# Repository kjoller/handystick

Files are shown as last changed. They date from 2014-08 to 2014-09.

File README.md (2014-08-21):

HandyStick is yet another small development board with an AtmegaX8 (Atmega88,
Atmega168, Atmega328). The board is targeted towards use with vUsb, a software
implemented USB stack.

It is cheap to manufacture, fitting two on a cheap 5x5cm 2-layer pcb, and using
easy-to-source parts.

Possible uses:

* Using projects like USBAspLoader, you can get a USB programmable AVR board for less than $3 in parts.
* You can use this for USB HID-devices, such as joysticks, gamepads or even a full-featured MAME cabinet
* USB dataloggers
* For more ideas, see the vUSB web site.

The first panel is panelised with mouse bites (tab routing), so not all PCB
services will take it. I have ordered the first batch on DirtyPCBs. 

(For added vendor flexibility, it would be wise to panelize it using only
silkscreen seperators. with just silkscreen, 5 should fit easily on a 5x10cm
board, making it even cheaper.)

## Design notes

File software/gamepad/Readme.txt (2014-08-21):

This is the README file for the HIDKeys USB device.

HIDKeys is an example application for implementing an USB keyboard conforming
to the "USB Device Class Definition for Human Interface Devices (HID)". It is
based on Objective Development's firmware-only USB driver for Atmel's AVR
microcontrollers and accepts up to 17 key inputs on an ATMega8. The firmware
should be easily portable to an ATTiny2313 or other tiny devices. Since it
implements a standards compliant keyboard, no separate host software is
needed.

Objective Development's USB driver is a firmware-only implementation of the
USB 1.1 standard (low speed device) on cheap single chip microcomputers of
Atmel's AVR series, such as the ATtiny2313 or even some of the small 8 pin
devices. It implements the standard to the point where useful applications can
be implemented. See the file "usbdrdv/usbdrv.h" for features and limitations.

BUILDING AND INSTALLING
=======================
The firmware for HIDKeys requires avr-gcc and avr-libc (a C-library for
the AVR controller). Please read the instructions at
http://www.nongnu.org/avr-libc/user-manual/install_tools.html for how to
install the GNU toolchain (avr-gcc, assembler, linker etc.) and avr-libc.
If you are on Windows, download WinAVR (see http://winavr.sourceforge.net/).

Once you have the GNU toolchain for AVR microcontrollers installed, you can
run "make". You may have to edit the Makefile to use your preferred downloader
with "make flash". Our current version is built for uisp with the AVR910
serial programmer connected through a USB to serial adapter to a Mac running
Mac OS X. Before you download the firmware, run "make fuse" to configure the
device for an external crystal.

NEVER LET A DEVICE WITH THIS FIRMWARE ESCAPE YOUR LAB! It uses a Vendor-ID
which is dedicated to education only. See the remarks in usbconfig.h and the
design hints below.

FILES IN THE DISTRIBUTION
=========================
Readme.txt ........ The file you are currently reading.
main.c ............ Source code of the controller firmware.
Makefile .......... The makefile for compiling the firmware.
checksize ......... A utility to check the code size (used by Makefile).
usbconfig.h ....... Header file with configuration options for the driver.
usbdrv ............ USB driver -- See Readme.txt in that directory for info.
circuit ........... Circuit diagrams in PDF and EAGLE 4 format. A free version
                    of EAGLE is available for Linux, Mac OS X and Windows from
                    http://www.cadsoft.de/.
License.txt ....... Public license (GPL2) for all contents of this project.
Changelog.txt ..... Logfile documenting changes in soft-, firm- and hardware.

WHY SHOULD I IMPLEMENT MY DEVICE AS A HID?
==========================================
HID does not necessarily mean keyboards, mice and joysticks. Any device which
requires only a moderate transfer rate can be designed as HID. So, should you
make a HID or a custom device with its own driver? The answer depends mostly
on the targetted operating system.

The main advantage of a HID compliant device is that you don't need a kernel
driver on Windows. This means that you can start the controlling software
application WITHOUT installation by an Administrator, e.g. directly from CD.
Since other operating systems don't need a kernel driver for USB devices, this
advantage is mostly Windows-only. The main disadvantage is the added
complexity (you need to understand how Report Descriptors are built) and that
you must conform to the framework defined by the HID specification.

Writing your own driver (e.g. with libusb) gives you much more flexibility and
less complexity, but you must install a kernel driver on Windows.

HINTS FOR DESIGNING YOUR OWN HID
================================
Designing a keyboard, mouse or joystick is relatively easy. There are enough
example Report Descriptors available and you can start with these. But if you
design something like e.g. our PowerSwitch, you must try to fit it into the
framework of "HID Usages" defined in usb.org's "HID Usage Tables" document.
The hints given here are mostly for this case:

(1) Use usb.org's "HID Descriptor Tool" available from
http://www.usb.org/developers/hidpage/ to build the Report Descriptor. You can
save the descriptor as "C" header file in the "Save As..." dialog.

(2) NEVER declare your device as keyboard or mouse, unless it actually IS a
keyboard or mouse. Keyboards and mice are hogged by the operating system
immediately after they have been connected.

(3) If you convert a keyboard or mouse into something different (by modifying
the Report Descriptor), you must delete the device in the Windows Device
Manager. Otherwise Windows will still bind the keyboard or mouse driver to the
device because this binding is established to the Vendor- and Product-ID, not
the device class.

(4) NEVER use Objective Development's free shared VID/PID pair for HIDs. Since
Windows binds the driver by VID/PID, you would bind the HID driver instead of
libusb to the IDs.

(5) Windows is very strict (more than usb.org's Descriptor Tool) when checking
Report Descriptors. If the descriptor check fails, the device will not even be
listed as HID.

(6) Windows checks reports against the Report Descriptor. If your device sends
more or less data than specified in the descriptor, the message is discarded.

(7) Use a USB Sniffer if something does not work as expected. You can usually
see where the communication aborts.

(8) Here is an example Report Descriptor to start with. It defines one input
report with up to 7 bytes for receiving interrupts from the device and 3
feature reports for reading/writing data from/to the device in blocks of 7, 15
or 31 bytes. Each report is prefixed by its report ID for a total of 8, 16 or
32 bytes. All blocks are defined as opaque data buffers with no particular
usage.

    0x06, 0x00, 0xff,              // USAGE_PAGE (Vendor Defined Page 1)
    0x09, 0x01,                    // USAGE (Vendor Usage 1)
    0xa1, 0x01,                    // COLLECTION (Application)
    0x15, 0x00,                    //   LOGICAL_MINIMUM (0)
    0x26, 0xff, 0x00,              //   LOGICAL_MAXIMUM (255)
    0x75, 0x08,                    //   REPORT_SIZE (8)
    0x85, 0x01,                    //   REPORT_ID (1)
    0x95, 0x07,                    //   REPORT_COUNT (7)
    0x09, 0x00,                    //   USAGE (Undefined)
    0x82, 0x02, 0x01,              //   INPUT (Data,Var,Abs,Buf)
    0x85, 0x02,                    //   REPORT_ID (2)
    0x95, 0x07,                    //   REPORT_COUNT (7)
    0x09, 0x00,                    //   USAGE (Undefined)
    0xb2, 0x02, 0x01,              //   FEATURE (Data,Var,Abs,Buf)
    0x85, 0x03,                    //   REPORT_ID (3)
    0x95, 0x0f,                    //   REPORT_COUNT (15)
    0x09, 0x00,                    //   USAGE (Undefined)
    0xb2, 0x02, 0x01,              //   FEATURE (Data,Var,Abs,Buf)
    0x85, 0x04,                    //   REPORT_ID (4)
    0x95, 0x1f,                    //   REPORT_COUNT (31)
    0x09, 0x00,                    //   USAGE (Undefined)
    0xb2, 0x02, 0x01,              //   FEATURE (Data,Var,Abs,Buf)
    0xc0                           // END_COLLECTION

ABOUT THE LICENSE
=================
It is our intention to make our USB driver and this demo application
available to everyone. Moreover, we want to make a broad range of USB
projects and ideas for USB devices available to the general public. We
therefore want that all projects built with our USB driver are published
under an Open Source license. Our license for the USB driver and demo code is
the GNU General Public License Version 2 (GPL2). See the file "License.txt"
for details.

If you don't want to publish your source code under the GPL2, you can simply
pay money for AVR-USB. As an additional benefit you get USB PIDs for free,
licensed exclusively to you. See the file "CommercialLicense.txt" for details.

MORE INFORMATION
================
For more information about Objective Development's firmware-only USB driver
for Atmel's AVR microcontrollers please visit the URL

    http://www.obdev.at/products/avrusb/

A technical documentation of the driver's interface can be found in the file
"usbdrv/usbdrv.h".

--
(c) 2006, 2007 by OBJECTIVE DEVELOPMENT Software GmbH.
http://www.obdev.at/

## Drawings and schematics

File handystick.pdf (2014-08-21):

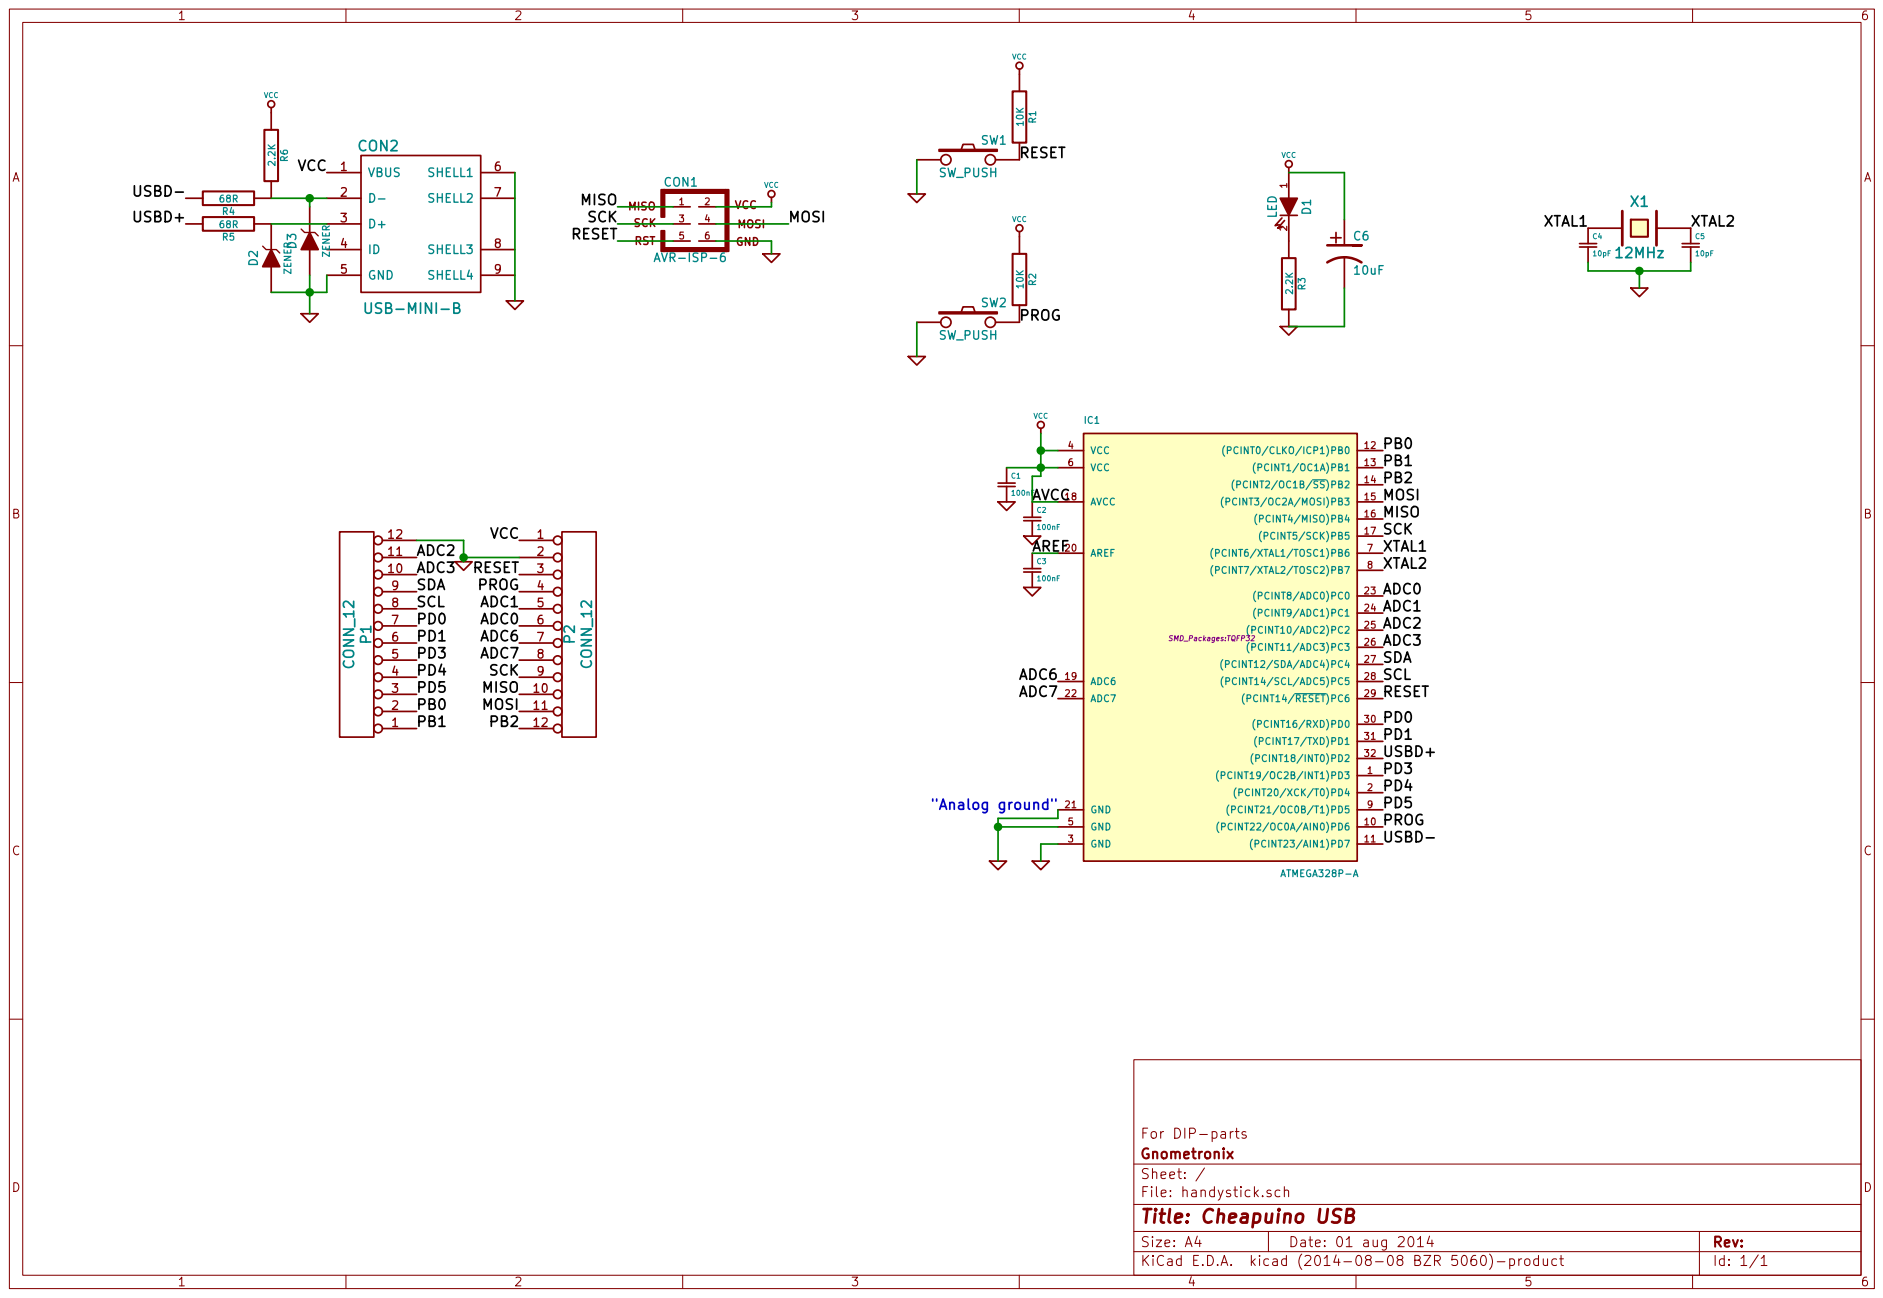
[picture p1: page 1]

File: handystick.sch Sheet: / Gnometronix For DIP-parts

Id: 1/1 Title: Cheapuino USB

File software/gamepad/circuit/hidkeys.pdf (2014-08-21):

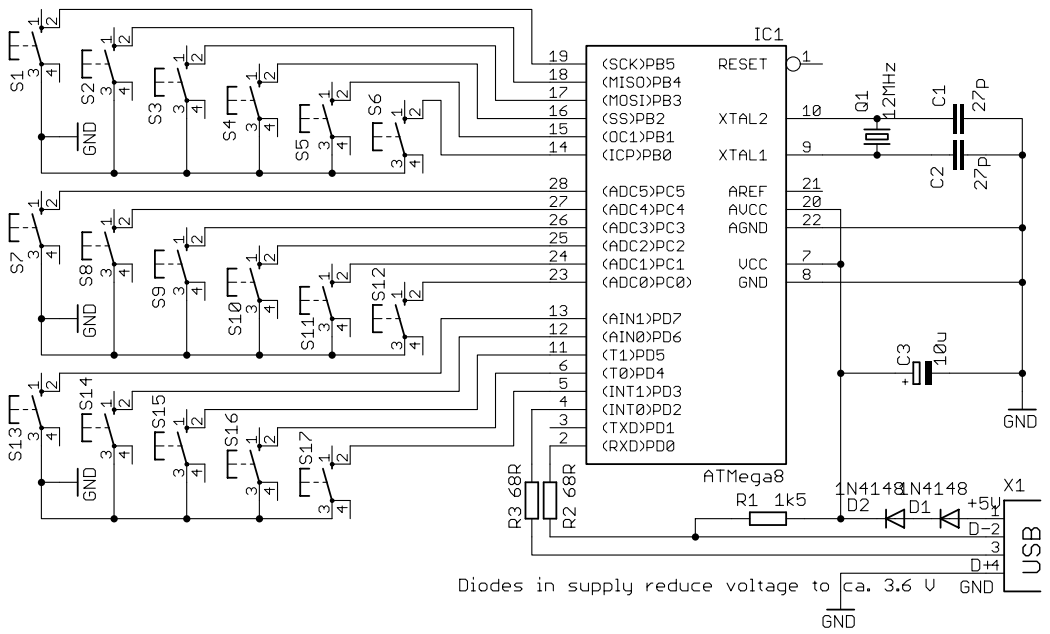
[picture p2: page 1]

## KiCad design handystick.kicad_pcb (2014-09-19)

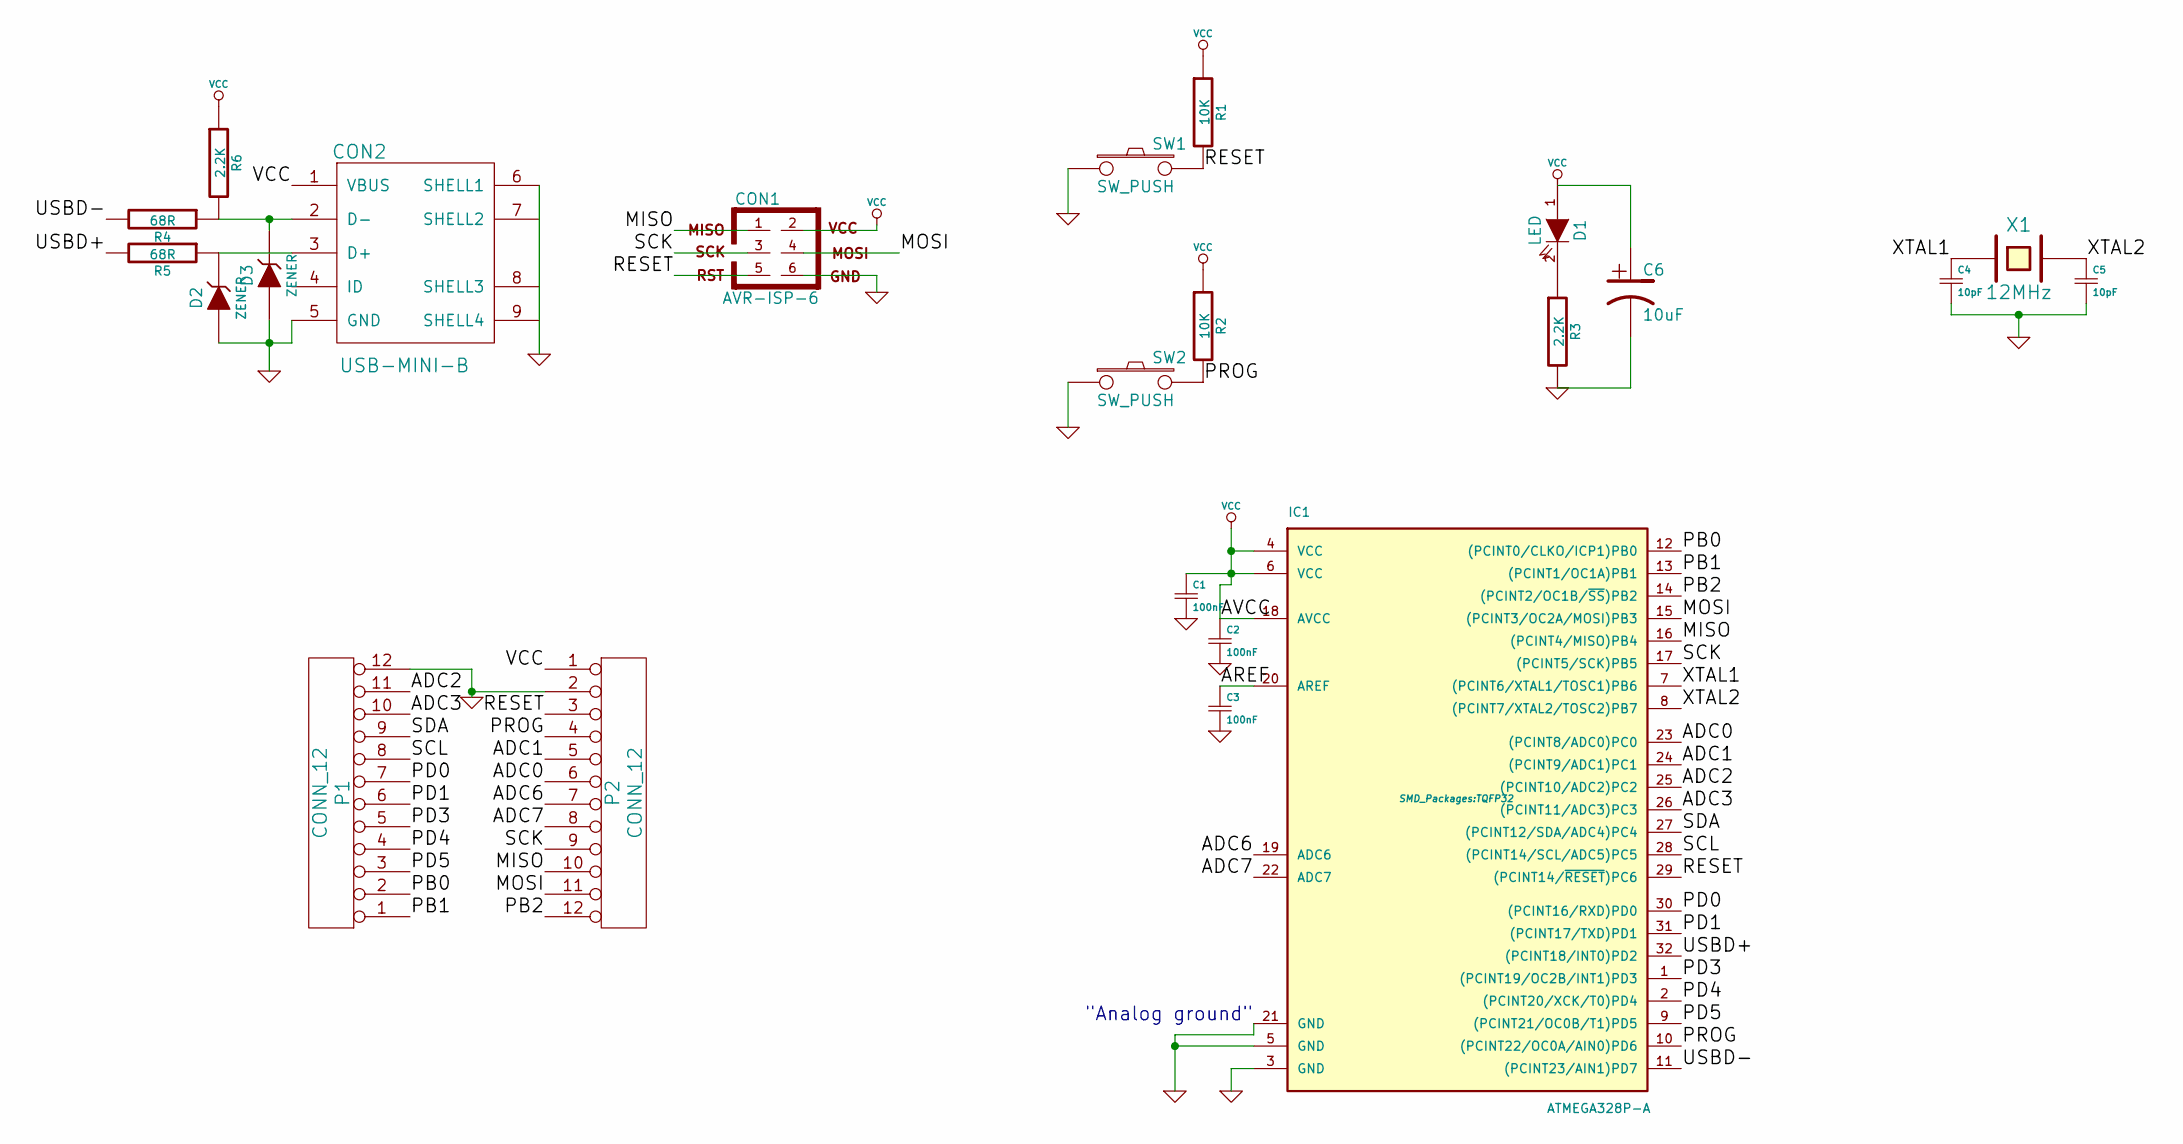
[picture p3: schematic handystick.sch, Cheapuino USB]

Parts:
C1, C2, C3: 100nF; SMD_0603
C4, C5: 10pF; c_0805
C6: 10uF
CON1: AVR-ISP-6; Pin_Header_Straight_2x03
CON2: USB-MINI-B; USB_Micro_B_SMD+DIP_long
D1: LED; SMD_0805
D2, D3: ZENER; Diode-MiniMELF_Handsoldering
IC1: ATMEGA328P-A; TQFP32
P1, P2: CONN_12; Pinrow_12p_oval
R1, R2: 10K; SMD_0603
R3, R6: 2.2K; SMD_0603
R4, R5: 68R; SMD_0805
SW1, SW2: SW_PUSH; 3x6_smd_button
X1: 12MHz; crystal_5032_2p

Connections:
/ADC0: IC1.23 ((PCINT8/ADC0)PC0), P2.6
/ADC1: IC1.24 ((PCINT9/ADC1)PC1), P2.5
/ADC2: IC1.25 ((PCINT10/ADC2)PC2), P1.11
/ADC3: IC1.26 ((PCINT11/ADC3)PC3), P1.10
/ADC6: IC1.19 (ADC6), P2.7
/ADC7: IC1.22 (ADC7), P2.8
/AREF: C3.1, IC1.20 (AREF)
/MISO: CON1.1, IC1.16 ((PCINT4/MISO)PB4), P2.10
/MOSI: CON1.4, IC1.15 ((PCINT3/OC2A/MOSI)PB3), P2.11
/PB0: IC1.12 ((PCINT0/CLKO/ICP1)PB0), P1.2
/PB1: IC1.13 ((PCINT1/OC1A)PB1), P1.1
/PB2: IC1.14 ((PCINT2/OC1B/~SS~)PB2), P2.12
/PD0: IC1.30 ((PCINT16/RXD)PD0), P1.7
/PD1: IC1.31 ((PCINT17/TXD)PD1), P1.6
/PD3: IC1.1 ((PCINT19/OC2B/INT1)PD3), P1.5
/PD4: IC1.2 ((PCINT20/XCK/T0)PD4), P1.4
/PD5: IC1.9 ((PCINT21/OC0B/T1)PD5), P1.3
/PROG: IC1.10 ((PCINT22/OC0A/AIN0)PD6), P2.4, R2.2, SW2.2
/RESET: CON1.5, IC1.29 ((PCINT14/~RESET~)PC6), P2.3, R1.2, SW1.2
/SCK: CON1.3, IC1.17 ((PCINT5/SCK)PB5), P2.9
/SCL: IC1.28 ((PCINT14/SCL/ADC5)PC5), P1.8
/SDA: IC1.27 ((PCINT12/SDA/ADC4)PC4), P1.9
/USBD+: IC1.32 ((PCINT18/INT0)PD2), R5.2
/USBD-: IC1.11 ((PCINT23/AIN1)PD7), R4.2
/XTAL1: C4.1, IC1.7 ((PCINT6/XTAL1/TOSC1)PB6), X1.1
/XTAL2: C5.1, IC1.8 ((PCINT7/XTAL2/TOSC2)PB7), X1.2
GND: C1.2, C2.2, C3.2, C4.2, C5.2, C6.2, CON1.6, CON2.5 (GND), CON2.6 (SHELL1), CON2.7 (SHELL2), CON2.8 (SHELL3), CON2.9 (SHELL4), D2.1 (A), D3.1 (A), IC1.3 (GND), IC1.5 (GND), IC1.21 (GND), P1.12, P2.2, R3.2, SW1.1, SW2.1; also elsewhere on the board
unnamed: CON2.2 (D-), D3.2 (K), R4.1, R6.2
unnamed: CON2.3 (D+), D2.2 (K), R5.1
unnamed: D1.2 (K), R3.1
VCC: C1.1, C2.1, C6.1, CON1.2, CON2.1 (VBUS), D1.1 (A), IC1.4 (VCC), IC1.6 (VCC), IC1.18 (AVCC), P2.1, R1.1, R2.1, R6.1

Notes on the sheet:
"Analog ground"

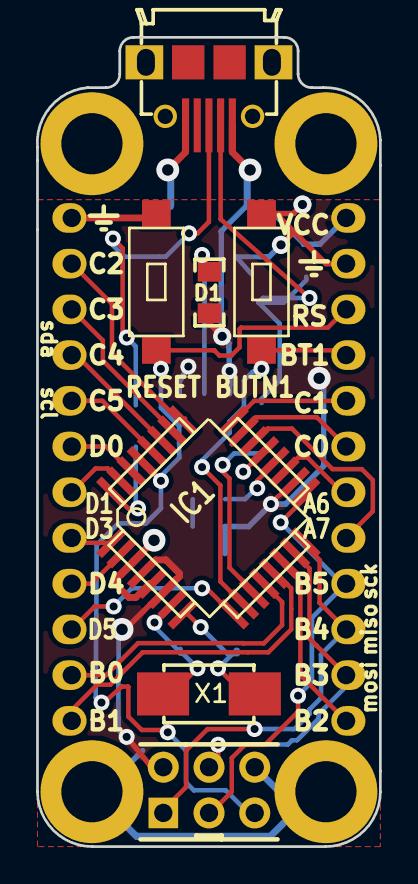
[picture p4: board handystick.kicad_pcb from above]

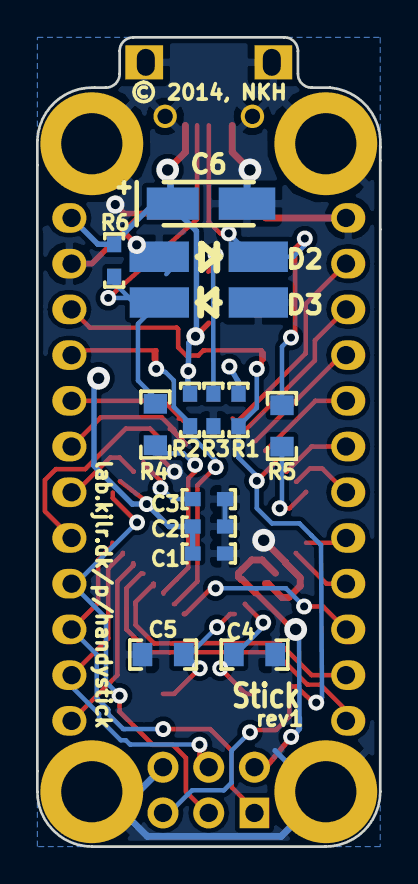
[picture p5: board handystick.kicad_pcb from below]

Board: 2 copper layers, 19.1 x 45.0 mm, 27 parts (14 on the bottom side), 31 nets.

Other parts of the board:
1PIN, 1PIN#2, 1PIN#3, 1PIN#4: P***; M3_mounting_hole

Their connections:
GND: 1PIN.1, 1PIN#2.1, 1PIN#3.1, 1PIN#4.1; also elsewhere on the board

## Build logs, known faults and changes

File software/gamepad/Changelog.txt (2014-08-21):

This file documents changes in the software, firmware and hardware of the
HIDKeys device. New entries are always appended to the end of the file.
Scroll down to the bottom to see the most recent changes.

* Release 2006-02-07

- Updated to new version of USB driver. This version has major bugfixes. See
  Changelog in usbdrv directory for more details.

* Release 2006-03-14

- Added series diodes (for voltage reduction) in supply in circuit diagram.
- Updated to new driver version.
- Changed License to GPL2

* Release 2007-03-29

- Updated to newest version of v-usb.
- Fixed errors reported by gcc 4.6.2.

* Release 2012-12-08

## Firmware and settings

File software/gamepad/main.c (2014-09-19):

#include <avr/io.h>
#include <avr/interrupt.h>
#include <avr/pgmspace.h>
#include <avr/wdt.h>
#include "usbdrv.h"

#include <util/delay.h>

static void hardwareInit(void)
{
//    PORTB = 0xff;   /* activate all pull-ups */
    DDRB = 0b00100000;       /* all pins input */
//    PORTC = 0xff;   /* activate all pull-ups */
    DDRC = 0;       /* all pins input */
    DDRD =  0b10000100;   /* 0000 0111 bin: all pins input except USB (-> USB reset) */
    DDRD = 0x02;    /* 0000 0010 bin: remove USB reset condition */
}

uchar sentMask;
uchar readMask;

/* ------------------------------------------------------------------------- */
/* ----------------------------- USB interface ----------------------------- */
/* ------------------------------------------------------------------------- */

static uchar    idleRate;           /* in 4 ms units */

const PROGMEM char usbHidReportDescriptor[42] = {   /* USB report descriptor */
    0x05, 0x01,                    // USAGE_PAGE (Generic Desktop)
    0x09, 0x05,                    // USAGE (Keyboard)
    0xa1, 0x01,                    // COLLECTION (Application)
    0xa1, 0x00,                    //  COLLECTION (Physical)
    0x05, 0x09,                    //   USAGE_PAGE (Button)
    0x19, 0x01,                    //   USAGE_MINIMUM (Button 1)
    0x29, 0x04,                    //   USAGE_MAXIMUM (Button 4)
    0x15, 0x00,                    //   LOGICAL_MINIMUM (0)
    0x25, 0x01,                    //   LOGICAL_MAXIMUM (1)
    0x95, 0x04,                    //   REPORT_COUNT (4)
    0x75, 0x01,                    //   REPORT_SIZE (1)
    0x81, 0x02,                    //   INPUT (Data,Var,Abs)

    0x05, 0x01,                    //   USAGE_PAGE (Generic Desktop)
    0x09, 0x30,                    //   USAGE(X)
    0x09, 0x31,                    //   USAGE(Y)
    0x15, 0xff,                    //   LOGICAL_MINIMUM (-1)
    0x25, 0x01,                    //   LOGICAL_MAXIMUM (1)
    0x95, 0x02,                    //   REPORT_COUNT (2)
    0x75, 0x02,                    //   REPORT_SIZE (2)
    0x81, 0x02,                    //   INPUT (Data,Var,Abs)
    0xc0,                          // END_COLLECTION
    0xc0                           // END_COLLECTION
};

typedef struct {
   uchar buttonMask;
} report_t;

static report_t reportBuffer;
static uchar    idleRate;



usbMsgLen_t usbFunctionSetup(uchar data[8]) {
    usbRequest_t *rq = (void *)data;

    // The following requests are never used. But since they are required by
    // the specification, we implement them in this example.
    if((rq->bmRequestType & USBRQ_TYPE_MASK) == USBRQ_TYPE_CLASS) {
        if(rq->bRequest == USBRQ_HID_GET_REPORT) {  
            // wValue: ReportType (highbyte), ReportID (lowbyte)
            usbMsgPtr = (void *)&reportBuffer; // we only have this one
            return sizeof(reportBuffer);
        } else if(rq->bRequest == USBRQ_HID_GET_IDLE) {
            usbMsgPtr = &idleRate;
            return 1;
        } else if(rq->bRequest == USBRQ_HID_SET_IDLE) {
            idleRate = rq->wValue.bytes[1];
        }
    }
    
    return 0; // by default don't return any data
}


/* ------------------------------------------------------------------------- */


// Interrupt for Port D (Where the arrows are)
ISR(PCINT1_vect) {
    readMask &= 0b00001111;
    // Right or left?
    if (!(PINC & (1<<PC5))) {       // If left is pushed set bit 6 and 
		readMask |= (3<<4);      // 7 to '11' (-1)
	} else if (!(PINC & (1<<PC3))) { // If right is pushed, set bit 6 and
		readMask |= (1<<4);      // 7 to '01' (1)
        readMask &= ~(1<<5);
	}                            // bits to '00' (0) - neutral.

	// Up or down?
    if (!(PINC & (1<<PC4))) {        // If up
		readMask |= (3<<6);
	} else if (!(PINC & (1<<PC2))) {  // If down
		readMask |= (1<<6);
        readMask &= ~(1<<7);
	}
}

// Interrupt for Port B (Where the buttons are)
ISR(PCINT0_vect) {
    readMask &= 0b11110000;
	if (!(PINB & (1<<PB3))) readMask |= 1;
	if (!(PINB & (1<<PB2))) readMask |= 1<<1;
	if (!(PINB & (1<<PB4))) readMask |= 1<<2;
	if (!(PINB & (1<<PB1))) readMask |= 1<<3;
}

void initButtonInterrupts(void) {
	PCICR |= (1<<PCIE1) | (1<<PCIE0);
	PCMSK1 |= (1<<PC5) | (1<<PC4) | (1<<PC3) | (1<<PC2);
	PCMSK0 |= (1<<PB1) | (1<<PB2) | (1<<PB3) | (1<<PB4);
}

int	main(void)
{
	uchar i;
	wdt_enable(WDTO_2S);
    hardwareInit();
    initButtonInterrupts();
	usbInit();
    usbDeviceDisconnect(); // enforce re-enumeration
    for(i = 0; i<250; i++) { // wait 500 ms
        wdt_reset(); // keep the watchdog happy
        _delay_ms(2);
    }
    usbDeviceConnect();

	sei();
	while(1) {
		wdt_reset();
        _delay_ms(20);
		usbPoll();
		
        if ((reportBuffer.buttonMask!=readMask)&(usbInterruptIsReady())){
            reportBuffer.buttonMask = readMask;
            usbSetInterrupt((void *)&reportBuffer, sizeof(reportBuffer));
			
        }
	}
	return 0;
}

/* ------------------------------------------------------------------------- */

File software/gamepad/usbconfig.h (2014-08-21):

/* Name: usbconfig.h
 * Project: AVR USB driver
 * Author: Christian Starkjohann
 * Creation Date: 2005-04-01
 * Tabsize: 4
 * Copyright: (c) 2005 by OBJECTIVE DEVELOPMENT Software GmbH
 * License: GNU GPL v2 (see License.txt) or proprietary (CommercialLicense.txt)
 * This Revision: $Id$
 */

#ifndef __usbconfig_h_included__
#define __usbconfig_h_included__

/*
General Description:
This file contains parts of the USB driver which can be configured and can or
must be adapted to your hardware.

Please note that the usbdrv contains a usbconfig-prototype.h file now. We
recommend that you use that file as a template because it will always list
the newest features and options.
*/

/* ---------------------------- Hardware Config ---------------------------- */

#define USB_CFG_CLOCK_KHZ       (F_CPU/1000)

#define USB_CFG_IOPORTNAME      D
/* This is the port where the USB bus is connected. When you configure it to
 * "B", the registers PORTB, PINB and DDRB will be used.
 */
#define USB_CFG_DMINUS_BIT      7
/* This is the bit number in USB_CFG_IOPORT where the USB D- line is connected.
 * This may be any bit in the port.
 */
#define USB_CFG_DPLUS_BIT       2
/* This is the bit number in USB_CFG_IOPORT where the USB D+ line is connected.
 * This may be any bit in the port. Please note that D+ must also be connected
 * to interrupt pin INT0!
 */

/* ----------------------- Optional Hardware Config ------------------------ */

/* #define USB_CFG_PULLUP_IOPORTNAME   D */
/* If you connect the 1.5k pullup resistor from D- to a port pin instead of
 * V+, you can connect and disconnect the device from firmware by calling
 * the macros usbDeviceConnect() and usbDeviceDisconnect() (see usbdrv.h).
 * This constant defines the port on which the pullup resistor is connected.
 */
/* #define USB_CFG_PULLUP_BIT          4 */
/* This constant defines the bit number in USB_CFG_PULLUP_IOPORT (defined
 * above) where the 1.5k pullup resistor is connected. See description
 * above for details.
 */

/* --------------------------- Functional Range ---------------------------- */

#define USB_CFG_HAVE_INTRIN_ENDPOINT    1
/* Define this to 1 if you want to compile a version with two endpoints: The
 * default control endpoint 0 and an interrupt-in endpoint 1.
 */
#define USB_CFG_HAVE_INTRIN_ENDPOINT3   0
/* Define this to 1 if you want to compile a version with three endpoints: The
 * default control endpoint 0, an interrupt-in endpoint 1 and an interrupt-in
 * endpoint 3. You must also enable endpoint 1 above.
 */
#define USB_CFG_IMPLEMENT_HALT          0
/* Define this to 1 if you also want to implement the ENDPOINT_HALT feature
 * for endpoint 1 (interrupt endpoint). Although you may not need this feature,
 * it is required by the standard. We have made it a config option because it
 * bloats the code considerably.
 */
#define USB_CFG_INTR_POLL_INTERVAL      10
/* If you compile a version with endpoint 1 (interrupt-in), this is the poll
 * interval. The value is in milliseconds and must not be less than 10 ms for
 * low speed devices.
 */
#define USB_CFG_IS_SELF_POWERED         0
/* Define this to 1 if the device has its own power supply. Set it to 0 if the
 * device is powered from the USB bus.
 */
#define USB_CFG_MAX_BUS_POWER           100
/* Set this variable to the maximum USB bus power consumption of your device.
 * The value is in milliamperes. [It will be divided by two since USB
 * communicates power requirements in units of 2 mA.]
 */
#define USB_CFG_IMPLEMENT_FN_WRITE      0
/* Set this to 1 if you want usbFunctionWrite() to be called for control-out
 * transfers. Set it to 0 if you don't need it and want to save a couple of
 * bytes.
 */
#define USB_CFG_IMPLEMENT_FN_READ       0
/* Set this to 1 if you need to send control replies which are generated
 * "on the fly" when usbFunctionRead() is called. If you only want to send
 * data from a static buffer, set it to 0 and return the data from
 * usbFunctionSetup(). This saves a couple of bytes.
 */
#define USB_CFG_IMPLEMENT_FN_WRITEOUT   0
/* Define this to 1 if you want to use interrupt-out (or bulk out) endpoint 1.
 * You must implement the function usbFunctionWriteOut() which receives all
 * interrupt/bulk data sent to endpoint 1.
 */
#define USB_CFG_HAVE_FLOWCONTROL        0
/* Define this to 1 if you want flowcontrol over USB data. See the definition
 * of the macros usbDisableAllRequests() and usbEnableAllRequests() in
 * usbdrv.h.
 */

/* -------------------------- Device Description --------------------------- */
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

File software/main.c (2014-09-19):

#include <avr/io.h>
#include <util/delay.h>

static void hardwareInit(void)
{
//    PORTB = 0xff;   /* activate all pull-ups */
    DDRB = 1<<PB5;       /* all pins input */
//    PORTC = 0xff;   /* activate all pull-ups */
}


int main(void)
{
    hardwareInit();
    while(1) {
        PORTB ^= 1<<PB5;
        _delay_ms(6000);
    }
    return 0;
}

/* ------------------------------------------------------------------------- */

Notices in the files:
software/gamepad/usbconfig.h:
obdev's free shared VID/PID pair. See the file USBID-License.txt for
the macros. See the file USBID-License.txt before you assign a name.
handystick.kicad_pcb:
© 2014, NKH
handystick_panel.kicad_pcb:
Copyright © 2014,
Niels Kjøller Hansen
